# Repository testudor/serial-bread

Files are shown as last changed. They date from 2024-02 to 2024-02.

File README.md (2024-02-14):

# Serial Bread

This is part of the "Modular Breadboard" parent project. 

It's a basic USB-to-UART adapter with a robust USB-C connector and switchable logic levels. It can also provide up to 3A@5v and 600mA@3<area>.3V for your project.
<!-- <area> prevents auto link generation caused by .3V -->

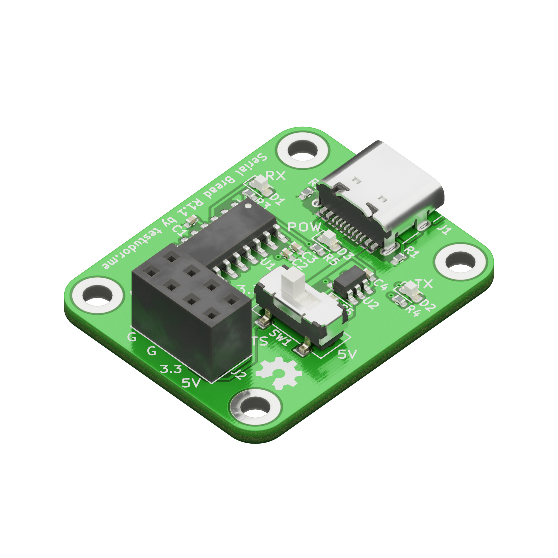
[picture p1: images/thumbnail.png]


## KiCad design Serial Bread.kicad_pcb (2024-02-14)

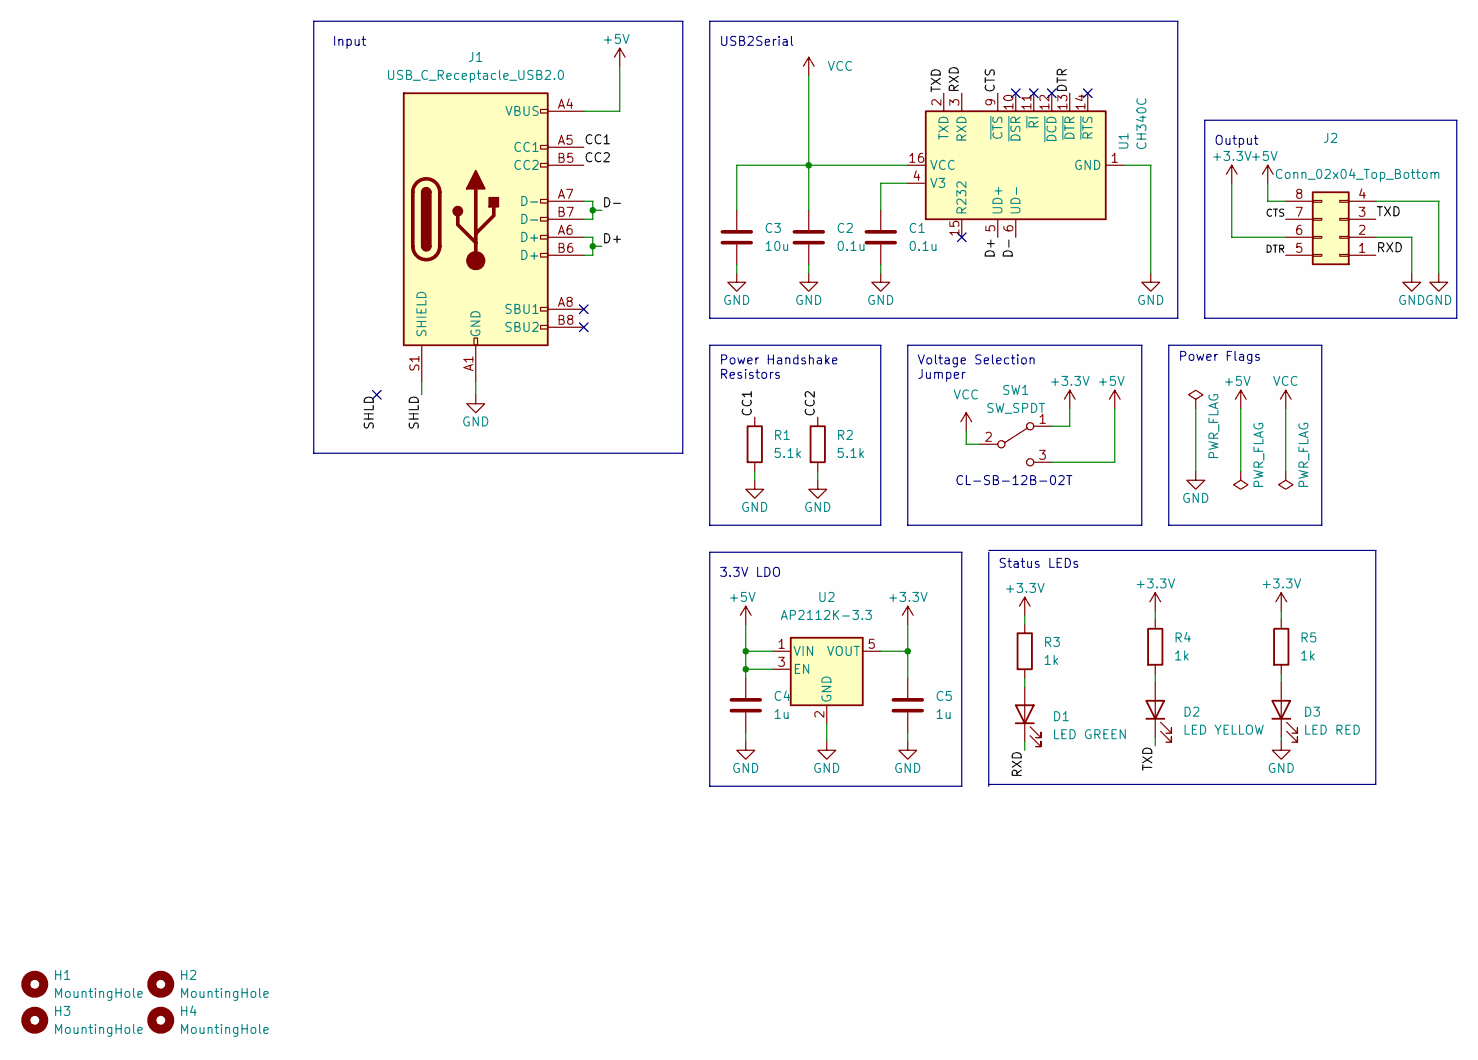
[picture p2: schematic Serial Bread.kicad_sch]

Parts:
C1, C2: 0.1u; C_0402_1005Metric; MPN C1525
C3: 10u; C_0402_1005Metric; MPN C15525
C4, C5: 1u; C_0402_1005Metric; MPN C52923
D1: LED GREEN; LED_0603_1608Metric; MPN C72043
D2: LED YELLOW; LED_0603_1608Metric; MPN C72038
D3: LED RED; LED_0603_1608Metric; MPN C2286
H1, H2, H3, H4: MountingHole; MountingHole_2.7mm_M2.5_ISO14580_Pad_TopBottom
J1: USB_C_Receptacle_USB2.0; USB_C_Receptacle_HRO_TYPE-C-31-M-12; MPN C165948
J2: Conn_02x04_Top_Bottom; PinSocket_2x04_P2.54mm_Vertical; MPN C358726
R1, R2: 5.1k; R_0402_1005Metric; MPN C25905
R3, R4, R5: 1k; R_0402_1005Metric; MPN C11702
SW1: SW_SPDT; CL-SB-12B-02T; MPN C2921648
U1: CH340C; SOIC-16_3.9x9.9mm_P1.27mm; MPN C84681
U2: AP2112K-3.3; SOT-23-5; MPN C51118

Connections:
+3.3V: C5.2, J2.6, R3.1, R4.1, R5.1, SW1.1 (A), U2.5 (VOUT)
+5V: C4.2, J1.A4 (VBUS), J1.A9 (VBUS), J1.B4 (VBUS), J1.B9 (VBUS), J2.8, SW1.3 (C), U2.1 (VIN), U2.3 (EN)
/CC1: J1.A5 (CC1), R1.1
/CC2: J1.B5 (CC2), R2.1
/CTS: J2.7, U1.9 (~CTS)
/D+: J1.A6 (D+), J1.B6 (D+), U1.5 (UD+)
/D-: J1.A7 (D-), J1.B7 (D-), U1.6 (UD-)
/DTR: J2.5, U1.13 (~DTR)
/RXD: D1.1 (K), J2.1, U1.3 (RXD)
/SHLD: J1.S1 (SHIELD)
/TXD: D2.1 (K), J2.3, U1.2 (TXD)
GND: C1.1, C2.1, C3.1, C4.1, C5.1, D3.1 (K), J1.A1 (GND), J1.A12 (GND), J1.B1 (GND), J1.B12 (GND), J2.2, J2.4, R1.2, R2.2, U1.1 (GND), U2.2 (GND)
unnamed: D1.2 (A), R3.2
unnamed: D2.2 (A), R4.2
unnamed: D3.2 (A), R5.2
unnamed: C1.2, U1.4 (V3)
VCC: C2.2, C3.2, SW1.2 (B), U1.16 (VCC)

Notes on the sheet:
Power Flags
CL-SB-12B-02T
Output
Power Handshake Resistors
Input
Voltage Selection Jumper
USB2Serial
Status LEDs
3.3V LDO

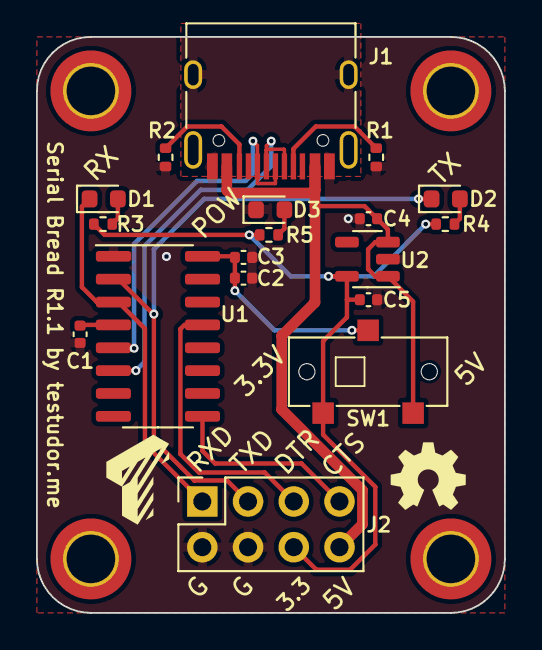
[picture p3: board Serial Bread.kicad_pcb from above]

Board: 2 copper layers, 26.0 x 32.0 mm, 22 parts (0 on the bottom side), 16 nets.

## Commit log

2022-12-31 change keepout zone display
    [Serial Bread.kicad_pcb]
2023-01-09 make copper fill clearance consistent
    [Serial Bread.kicad_pcb]
2023-01-09 Add missing pcbdraw modules
2023-01-09 make silkscreen consistent
    [Serial Bread.kicad_pcb]
2023-01-10 Add PCB side labels
2024-02-14 Initial commit R1.1
    [Serial Bread.kicad_pcb, Serial Bread.kicad_sch]
2024-02-14 Fixed missing OSHW silk
    [Serial Bread.kicad_pcb]
2024-02-14 Revert "Fixed missing OSHW silk"
    This reverts commit 2a56d455a99e7c22cc2508ea68d32a0d58d2fe36.
    [Serial Bread.kicad_pcb]
2024-02-14 Revert "Initial commit R1.1"
    This reverts commit dbca94149cb8df2c718ea664c1760d3caefabc82.
    [Serial Bread.kicad_pcb, Serial Bread.kicad_sch]
